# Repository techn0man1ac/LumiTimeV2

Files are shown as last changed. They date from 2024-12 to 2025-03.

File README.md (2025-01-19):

Attention, the project is under development, so it is subject to change.

# LumiTimeV2

LumiTimeV2 - this is the "Perpetual" Wristwatch(project code name "LumiTimeV2") with 12 red LEDs, it have LIR3032 Li-Ion battery and 12 solar cells, based on a Microchip microcontroller ATmega328P. It's full open source(firmware and hardware).

Next generation wristwatch after [12 LED ATtiny "Perpetual" Wristwatch](https://github.com/techn0man1ac/PerpetualLEDWristwatch). 

# Video demonstration:

/* Link may be here */

# How it's work?

/* Description may be here */

# How to set the time?

/* Description may be here */

# 3D model PCB:

The board is two-layer, with components on both sides. 

## PCB front view

On the front side of the board there are 12 microsolar panels in a circle and 12 red LEDs that display the time and the RTC with its quartz resonator:

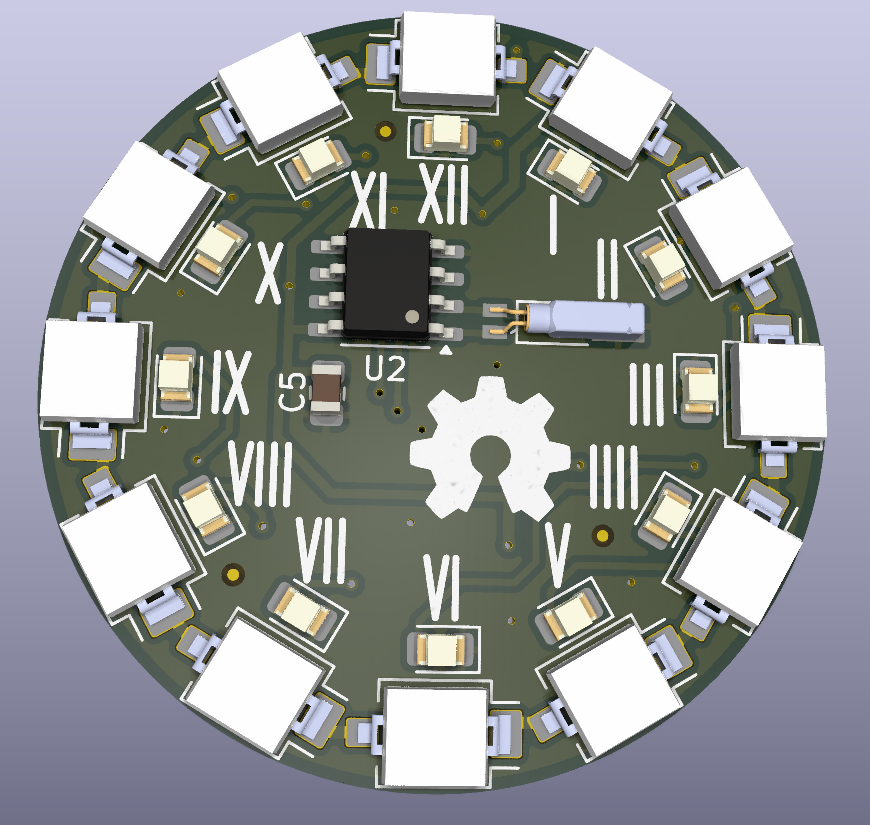
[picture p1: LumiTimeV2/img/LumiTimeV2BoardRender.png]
LumiTimeV2 PCB board render


## Back view

In the center of the board is the ATmega328 microcontroller(like Arduino Nano). Under LED III is a button used to display and set the time for the watch. All passive components of the circuit are of 0805 size, which allows them to be soldered without additional soldering equipment:

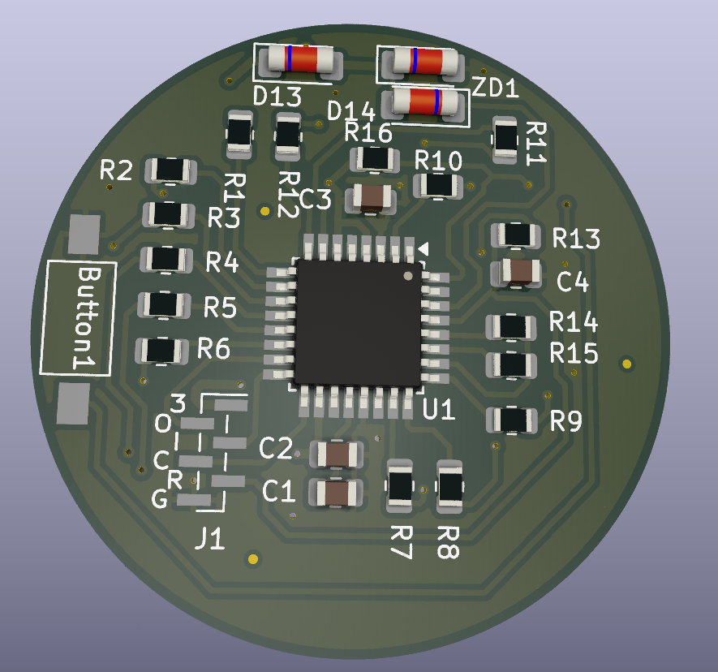
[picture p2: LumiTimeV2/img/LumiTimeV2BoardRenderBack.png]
LumiTimeV2 PCB board render back


PCB have 35 mm in the diameter:

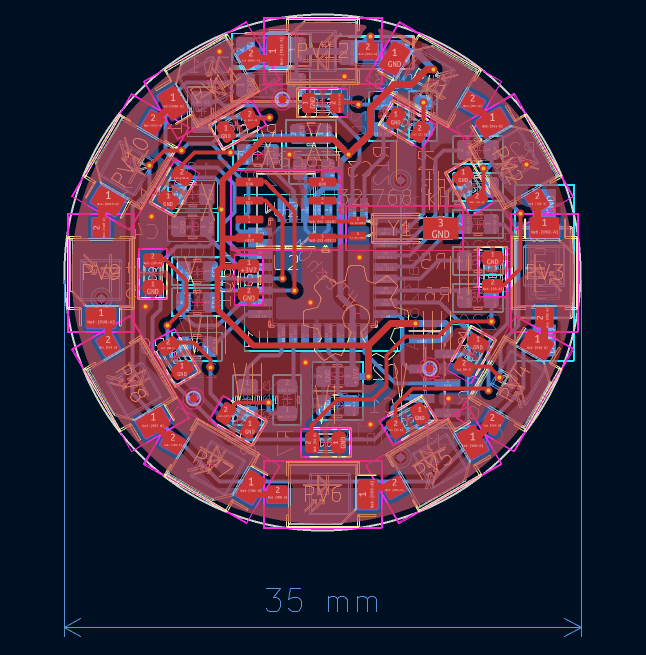
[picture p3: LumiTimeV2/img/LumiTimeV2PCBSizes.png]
LumiTimeV2 PCB board size


The thickness of the board is recommended to take 0.8mm otherwise it may not fit into the case.

# PCB gerber files:

Files for fabrication:

https://github.com/techn0man1ac/LumiTimeV2/tree/main/LumiTimeV2/PCB/Gerbers

# 3D model of PCB 

3D model in STEP format:

https://github.com/techn0man1ac/LumiTimeV2/tree/main/LumiTimeV2/PCB/3dModel

# Schematic

The circuitry of the clock provides for a sufficient number of parts, due to which the board is required to have parts on both sides. Here is a detailed description of each block on the schematic.

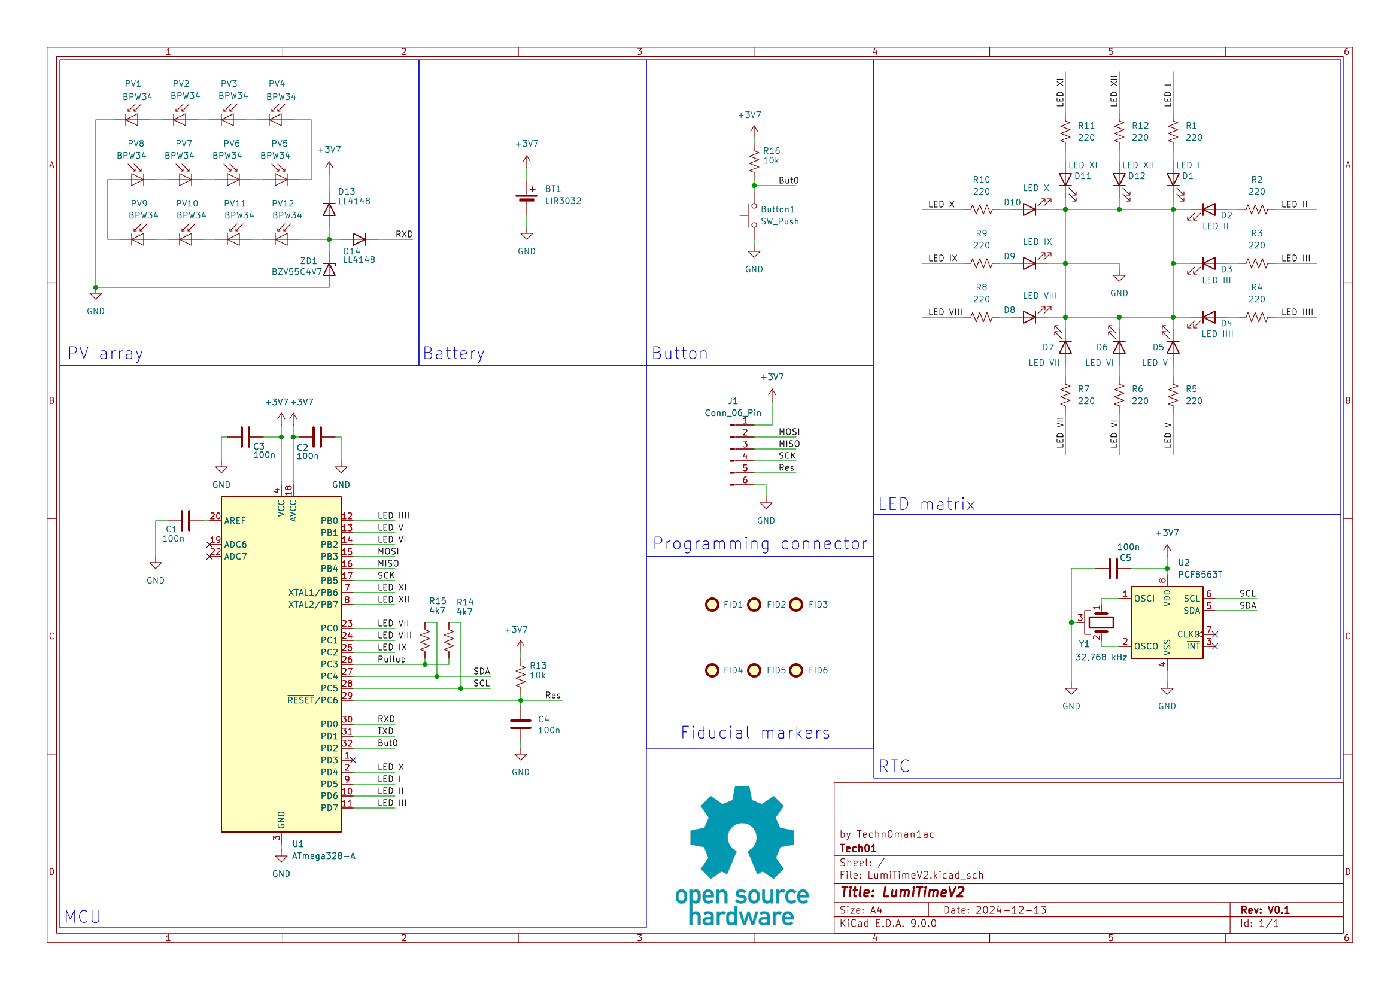
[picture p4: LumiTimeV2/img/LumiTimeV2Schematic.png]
LumiTimeV2 Schematic


## Charging system

The project uses 12 photodiodes BPW34S(PV array) that work like miniature solar panels, whose function is to charge the battery from light. 
The charging circuit is very primitive, since each micro-solar panel generates ~0.5V, if they are all 12 connected in series, the total voltage will be around 6 V, protect to overcharge the battery,used ZD1 Zener diode(4.7V), and a diode D13 is also prevent to reverse current(current flow into the solar panels) and add drop voltage 0.6-0.7V, as a result, we have a battery charging system with voltage like 4.0..4.1V. Charging current on a sunny day is ~2 mA.

## Battery

/* Description may be here */

## LEDs matrix

/* Description may be here */

## RTC

/* Description may be here */

## Programming connector

/* Description may be here */

## Microcontroller

/* Description may be here */

# Our mission and vision

It has a mission and vision that it borrowed from the [previous version](https://github.com/techn0man1ac/PerpetualLEDWristwatch) and carries the same values, such as:

## Mission:

To develop a simply and eco-friendly watch that integrates innovative technologies with minimal components, ensuring energy efficiency is within reach for all.

## Vision:

We aim to achieve a world where energy-saving technology is accessible to everyone, where our watch serves as a symbol of environmental stewardship and innovative solutions in energy efficiency.

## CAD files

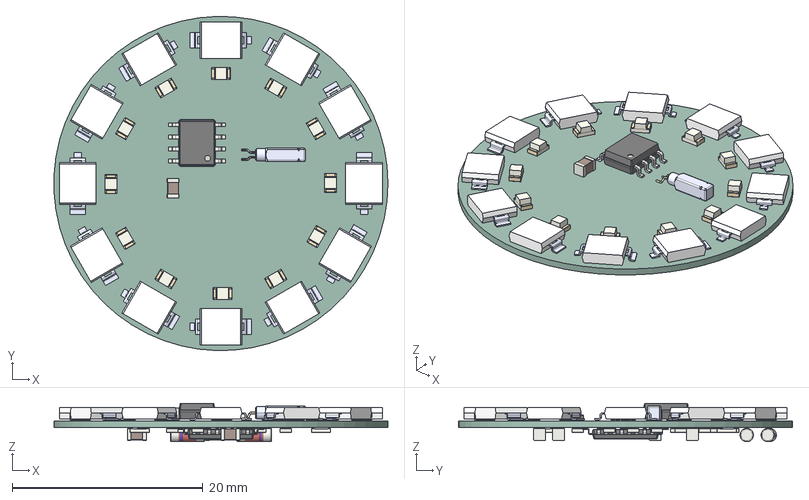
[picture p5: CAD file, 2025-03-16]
LumiTimeV2/PCB/3dModel/LumiTimeV2PCB.step
35.0 x 35.0 x 4.03 mm
BPW 34 S-Z--3DModel-STEP-56544 x 12
LED_0805_2012Metric x 12
SOIC-8_3.9x4.9mm_P1.27mm
MS3V-T1R-32.768KHZ-7PF-20PPM-TA-QC
C_0805_2012Metric x 5
R_0805_2012Metric x 16
TQFP-32_7x7mm_P0.8mm
D_MiniMELF x 3
LumiTimeV2_PCB

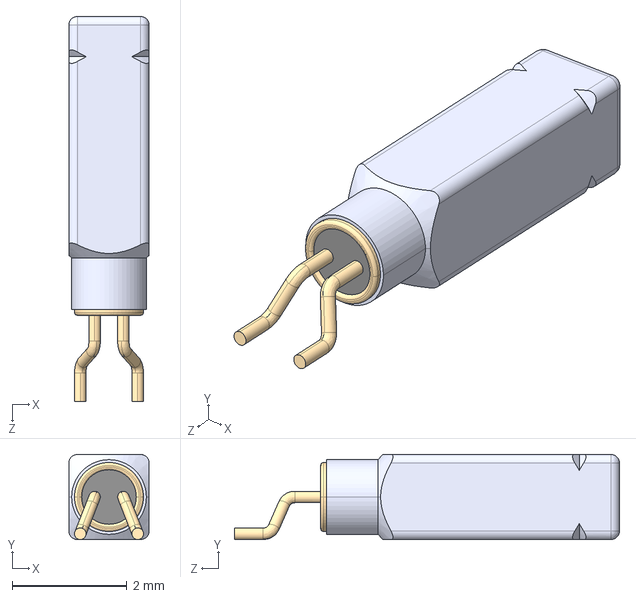
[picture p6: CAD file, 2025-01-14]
LumiTimeV2/PCB/KiCad/ComponetModels/MS3V-T1R-32.768KHZ-7PF-20PPM-TA-QC.step
1.40 x 1.48 x 6.70 mm

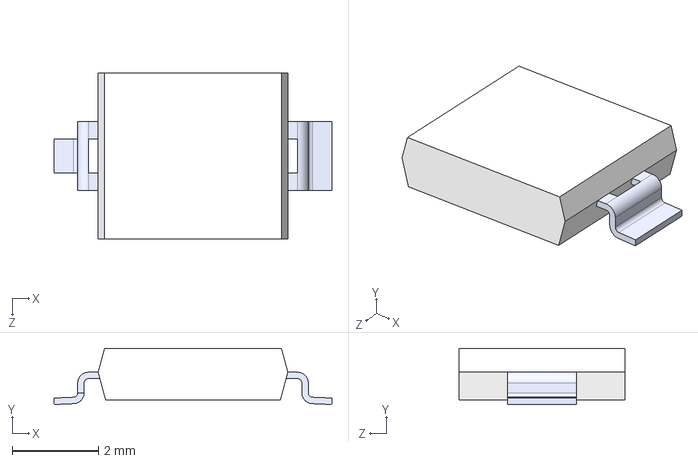
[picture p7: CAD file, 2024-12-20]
LumiTimeV2/PCB/KiCad/ComponetModels/BPW 34 S-Z--3DModel-STEP-56544.STEP
6.45 x 1.30 x 3.85 mm

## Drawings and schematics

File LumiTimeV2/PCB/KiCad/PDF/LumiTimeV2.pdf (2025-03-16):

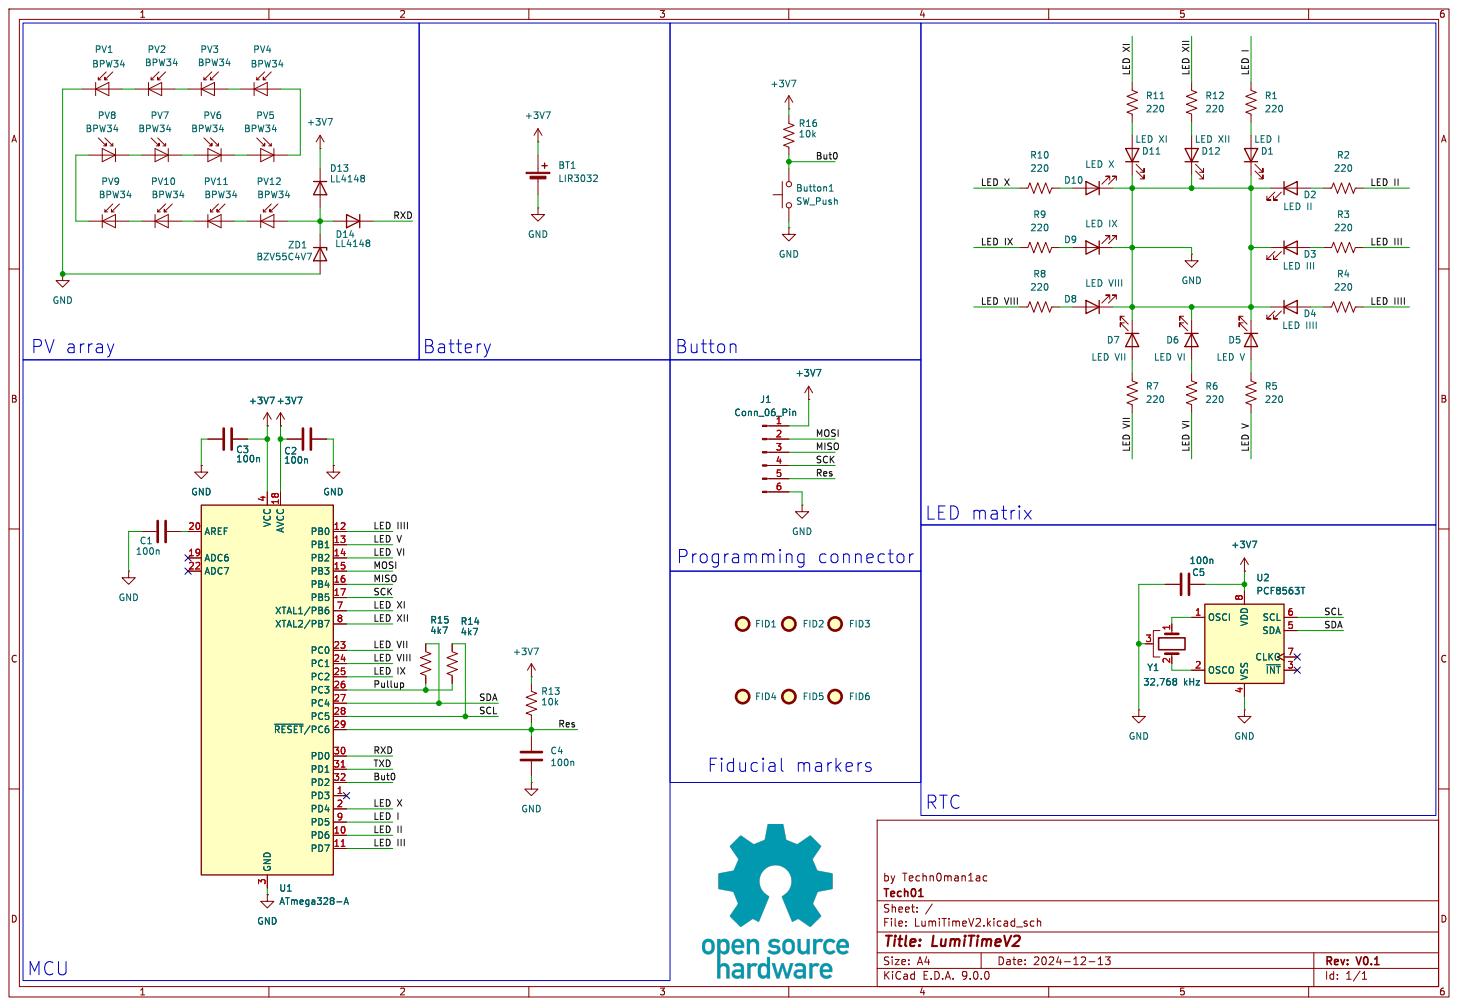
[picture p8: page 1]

LED VIII LED IX

LED III GND GND

LED VI LED VIII Pullup

4 SCL 6 SDA 5 CLKO 7 ~{INT}3 U2PCF8563T

4 SCL 6 SDA 5 CLKO 7 ~{INT}3 GND

Res LED II LED IX

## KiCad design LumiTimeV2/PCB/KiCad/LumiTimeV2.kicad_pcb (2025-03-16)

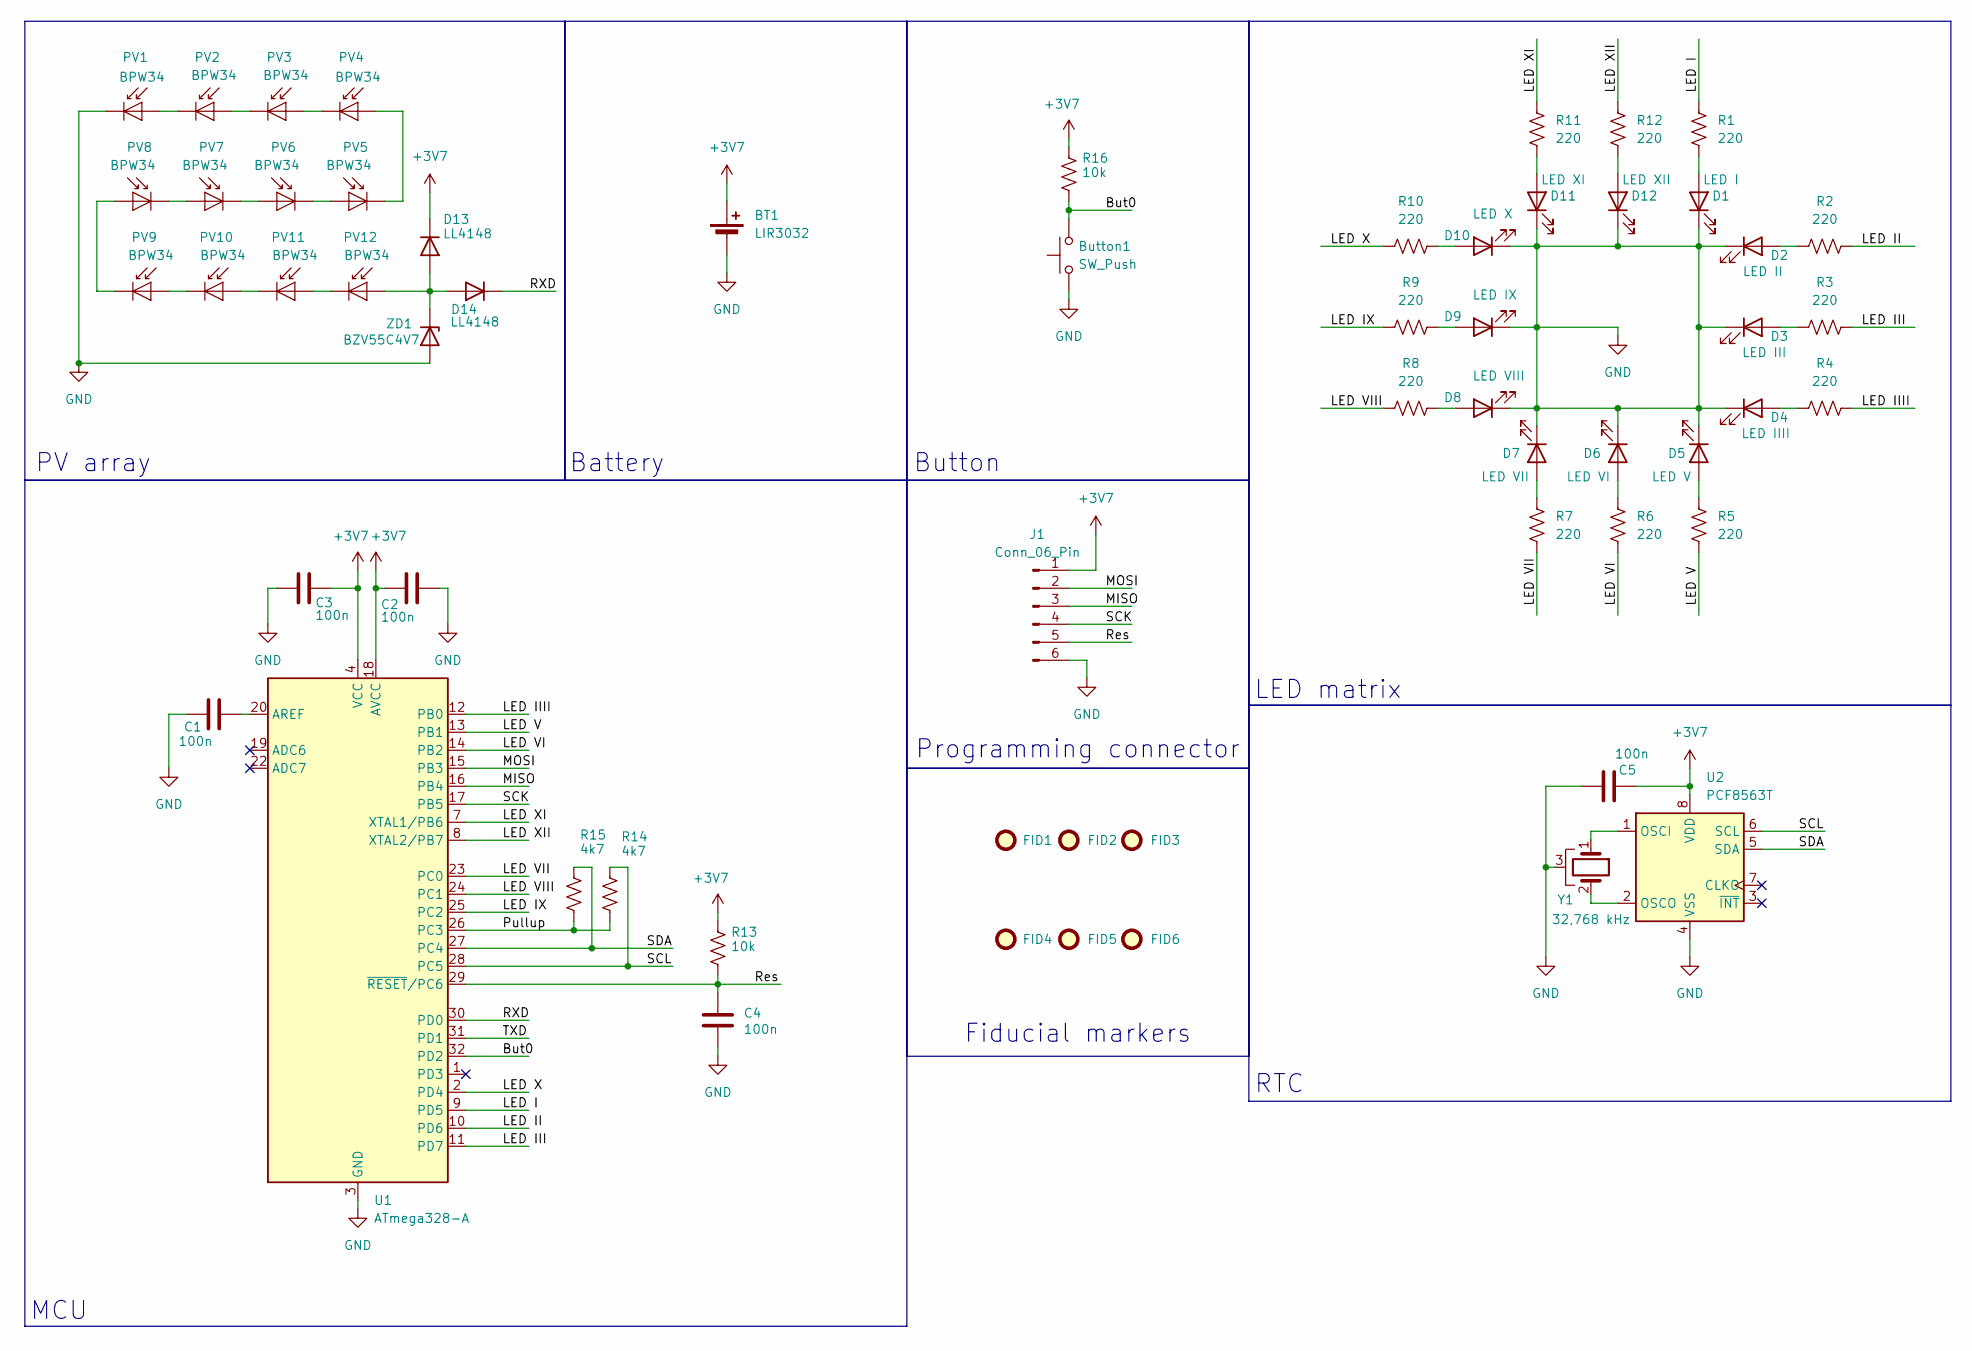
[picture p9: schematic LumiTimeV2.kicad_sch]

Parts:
BT1: LIR3032
Button1: SW_Push; SW_SPST_FSMSM
C1, C2, C3, C4, C5: 100n; C_0805_2012Metric
D1: LED I; LED_0805_2012Metric
D2: LED II; LED_0805_2012Metric
D3: LED III; LED_0805_2012Metric
D4: LED IIII; LED_0805_2012Metric
D5: LED V; LED_0805_2012Metric
D6: LED VI; LED_0805_2012Metric
D7: LED VII; LED_0805_2012Metric
D8: LED VIII; LED_0805_2012Metric
D9: LED IX; LED_0805_2012Metric
D10: LED X; LED_0805_2012Metric
D11: LED XI; LED_0805_2012Metric
D12: LED XII; LED_0805_2012Metric
D13, D14: LL4148; D_MiniMELF
FID1, FID2, FID3, FID4, FID5, FID6: Fiducial; Fiducial_0.5mm_Mask1mm
J1: Conn_06_Pin; PinHeader_1x06_P1.00mm_Vertical_SMD_Pin1Right
PV1, PV2, PV3, PV4, PV5, PV6, PV7, PV8, PV9, PV10, PV11, PV12: BPW34; Osram_BPW34S-SMD
R1, R2, R3, R4, R5, R6, R7, R8, R9, R10, R11, R12: 220; R_0805_2012Metric
R13, R16: 10k; R_0805_2012Metric
R14, R15: 4k7; R_0805_2012Metric
U1: ATmega328-A; TQFP-32_7x7mm_P0.8mm
U2: PCF8563T; SOIC-8_3.9x4.9mm_P1.27mm
Y1: 32,768 kHz; Crystal_SMD_MicroCrystal_MS3V-T1R
ZD1: BZV55C4V7; D_MiniMELF

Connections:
+3V7: BT1.1 (+), C2.1, C3.1, C5.1, D13.1 (K), J1.1, R13.1, R16.1, U1.4 (VCC), U1.6 (VCC), U1.18 (AVCC), U2.8 (VDD)
/But0: Button1.2, R16.2, U1.32 (PD2)
/LED I: R1.1, U1.9 (PD5)
/LED II: R2.2, U1.10 (PD6)
/LED III: R3.2, U1.11 (PD7)
/LED IIII: R4.2, U1.12 (PB0)
/LED IX: R9.1, U1.25 (PC2)
/LED V: R5.2, U1.13 (PB1)
/LED VI: R6.2, U1.14 (PB2)
/LED VII: R7.2, U1.23 (PC0)
/LED VIII: R8.1, U1.24 (PC1)
/LED X: R10.1, U1.2 (PD4)
/LED XI: R11.1, U1.7 (XTAL1/PB6)
/LED XII: R12.1, U1.8 (XTAL2/PB7)
/MISO: J1.3, U1.16 (PB4)
/MOSI: J1.2, U1.15 (PB3)
/Pullup: R14.2, R15.2, U1.26 (PC3)
/RXD: D14.1 (K), U1.30 (PD0)
/Res: C4.1, J1.5, R13.2, U1.29 (~RESET/PC6)
/SCK: J1.4, U1.17 (PB5)
/SCL: R14.1, U1.28 (PC5), U2.6 (SCL)
/SDA: R15.1, U1.27 (PC4), U2.5 (SDA)
/TXD: U1.31 (PD1)
GND: BT1.2 (-), Button1.1, C1.2, C2.2, C3.2, C4.2, C5.2, D1.1 (K), D2.1 (K), D3.1 (K), D4.1 (K), D5.1 (K), D6.1 (K), D7.1 (K), D8.1 (K), D9.1 (K), D10.1 (K), D11.1 (K), D12.1 (K), J1.6, PV1.1 (K), U1.3 (GND), U1.5 (GND), U1.21 (GND), U2.4 (VSS), Y1.3, ZD1.2 (A)
unnamed: D1.2 (A), R1.2
unnamed: D2.2 (A), R2.1
unnamed: D3.2 (A), R3.1
unnamed: D4.2 (A), R4.1
unnamed: D5.2 (A), R5.1
unnamed: D6.2 (A), R6.1
unnamed: D7.2 (A), R7.1
unnamed: D8.2 (A), R8.2
unnamed: D9.2 (A), R9.2
unnamed: D10.2 (A), R10.2
unnamed: D11.2 (A), R11.2
unnamed: D12.2 (A), R12.2
unnamed: D13.2 (A), D14.2 (A), PV12.2 (A), ZD1.1 (K)
unnamed: PV1.2 (A), PV2.1 (K)
unnamed: PV2.2 (A), PV3.1 (K)
unnamed: PV3.2 (A), PV4.1 (K)
unnamed: PV4.2 (A), PV5.1 (K)
unnamed: PV5.2 (A), PV6.1 (K)
unnamed: PV6.2 (A), PV7.1 (K)
unnamed: PV7.2 (A), PV8.1 (K)
unnamed: PV8.2 (A), PV9.1 (K)
unnamed: PV10.2 (A), PV11.1 (K)
unnamed: PV9.2 (A), PV10.1 (K)
unnamed: PV11.2 (A), PV12.1 (K)
unnamed: C1.1, U1.20 (AREF)
unnamed: U2.1 (OSCI), Y1.1
unnamed: U2.2 (OSCO), Y1.2

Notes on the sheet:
MCU
LED matrix
Programming connector
Battery
Button
RTC
PV array
Fiducial markers

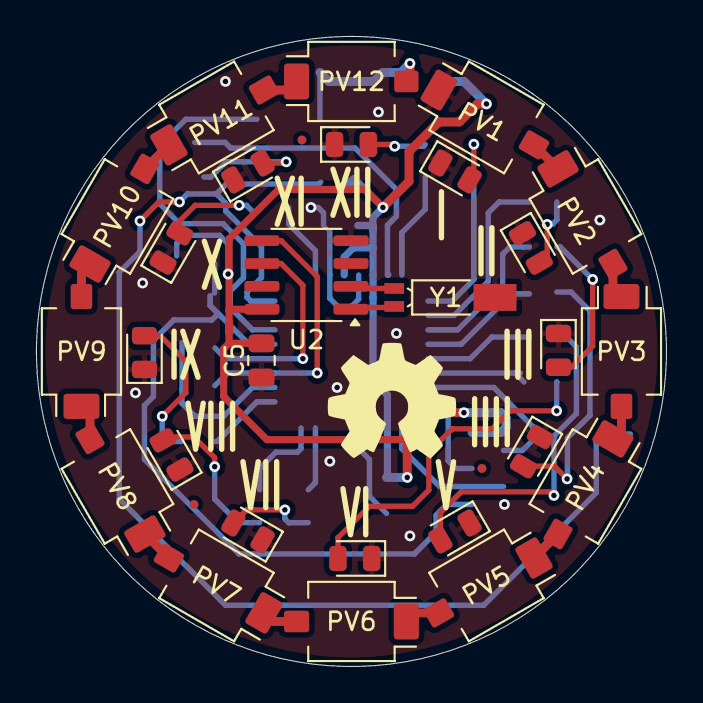
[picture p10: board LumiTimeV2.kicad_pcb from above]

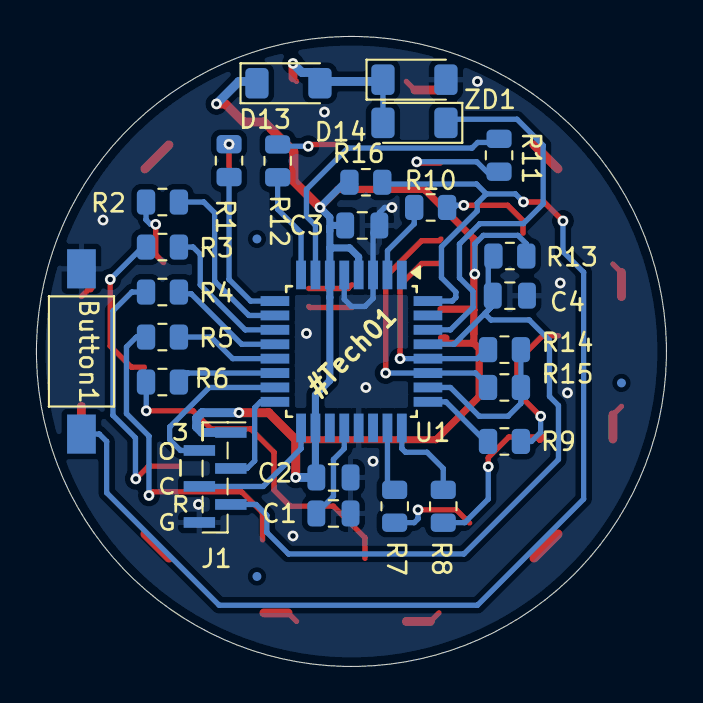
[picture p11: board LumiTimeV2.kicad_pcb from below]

Board: 2 copper layers, 35.0 x 35.0 mm, 60 parts (29 on the bottom side), 50 nets.

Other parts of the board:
OSHW: LOGO

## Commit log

2024-12-20 Change#00
    Add project KiCad files
    [BPW 34 S-Z--3DModel-STEP-56544.STEP, LumiTimeV2.kicad_pcb, LumiTimeV2.kicad_sch]
2024-12-20 Change#003
    Add PCB board render
2025-01-13 Change#004
    Delete files
    [BPW 34 S-Z--3DModel-STEP-56544.STEP, LumiTimeV2.kicad_pcb, LumiTimeV2.kicad_sch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]
2025-01-14 Change#005
    Add fresh project files
    [BPW 34 S-Z--3DModel-STEP-56544.STEP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]
2025-01-14 Change#005
    Delete PCB/KiCad/LumiTimeV2.kicad_prl
2025-01-15 Change#005
    Delete PCB directory
    [BPW 34 S-Z--3DModel-STEP-56544.STEP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]
2025-01-15 Change#006
    Add new files - final PCB version
    [BPW 34 S-Z--3DModel-STEP-56544.STEP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]
2025-01-15 Change#006
    Delete PCB/3dModel/LumiTimeV2PCB.stl
    [LumiTimeV2PCB.stl]
2025-01-18 Change#007
    Some new ideas
    [LumiTimeV2.kicad_pcb]
2025-01-19 Change#008
    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
    [BPW 34 S-Z--3DModel-STEP-56544.STEP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]
2025-01-19 Change#008
    Add new files in "LumiTimeV2" catalog
    [BPW 34 S-Z--3DModel-STEP-56544.STEP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]
2025-01-19 Change#008
    Delete LumiTimeV2/PCB/KiCad/fp-info-cache
2025-01-19 Change#008
    Delete LumiTimeV2/PCB/KiCad/LumiTimeV2.kicad_prl
2025-01-19 Change#008
    Add OSHW logo
    [LumiTimeV2.kicad_pcb, LumiTimeV2.kicad_sch]
2025-01-19 Change#008
    Rename Schematic.png to LumiTimeV2Schematic.png
2025-01-19 Change#008
    New gerber files
    [LumiTimeV2-B_Cu.gbr, LumiTimeV2-B_Mask.gbr, LumiTimeV2-B_Paste.gbr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]
2025-03-16 Change#010
    Add fiducial markers to PCB
    [BPW 34 S-Z--3DModel-STEP-56544.STEP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]
